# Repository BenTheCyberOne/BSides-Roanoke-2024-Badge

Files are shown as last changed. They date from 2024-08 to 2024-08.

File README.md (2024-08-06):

# Bsides Roanoke 2024 Badge
Public repo for the firmware source code, design files, and puzzle answers regarding the Bsides Roanoke 2024 Badge



## Index
/badge_fw: directory containing the badge's firmware and required libraries

/kiosk_fw: directory containing the kiosk's firmware and required libraries

/kiosk_server: directory containing the kiosk web application (scoreboard)

/badge_puzzles: directory containing the badge's puzzles and solutions

/badge_pcb: directory containing the badge's KiCAD design files

/badge_3d_parts: directory containing the badge's 3D printing (CAD) files

/kiosk_3d_parts: directory containing the kiosk's 3D printing (CAD) files

/results: directory containing the results of the BSides Roanoke 2024 Badge challenge

## Credits
This badge could not have been completed without the efforts of those below. Kudos to them!
- BenTheCyberOne
- Doc
- KoopaTroopa8

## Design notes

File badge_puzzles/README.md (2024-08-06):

# Badge Puzzle Solutions
Directory that holds the badge puzzles and their respective solutions. 

## Index
/Lights: Contains the puzzles, solutions for the light patterns that appeared in Puzzle Mode

/Printed: Contains the puzzles, solutions for the printed puzzles that appeared physically on the badge

/Serial: Contains the puzzles, solutions for the puzzles presented when using the serial commands in the badge

In total there were 11 puzzles (5 printed puzzles, 3 light puzzles inside of Puzzle Mode and 3 serial puzzles)

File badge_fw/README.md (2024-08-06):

# Badge Firmware
This directory holds the firmware and required libraries for the BSides Roanoke 2024 Badge

## ino
Because this firmware was built using Arduino IDE, the firmware is contained in one large .ino file. Arduino IDE made this firmware easy to develop, especially since I have never done something like this before. While it turned out to be quite a double-edged sword, Arduino IDE makes development of firmware for these small controllers quite an easy process. This folder also contains the compiled binary of the firmware, should you not want to build it yourself.

## lib
These are the external libraries used for the badge. 
- The PN532 library originally failed to function with our hardware, so alterations were made to ensure successful communication could happen between two badges.
- The NeoPixel library is unchanged and allows the NeoPixels on the board to function
- The EEPROM2 library is actually a modified version of the built-in "EEPROM" library of the Pico SDK. For some strange reason, there does not appear to be any libraries that allow easy control over sectors of flash via the rp2040. The original EEPROM library works by using up to the last 4KB of flash and storing it into RAM, allowing for quick read/write before commiting and saving to the real flash. EEPROM2 allows for sector selection (starting from the last 4KB sector). While not very memory-safe, it works perfectly for firmware that does not take a lot of space or code that does not utilize much of the RAM in the rp2040. Using this library (and a little computer science logic) we were able to quickly store and retrieve 3 different 4KB data structures stored in flash.

## How to build
1. Download Arduino IDE here: https://www.arduino.cc/en/software
2. Install the RP2040 device/board files: https://learn.adafruit.com/rp2040-arduino-with-the-earlephilhower-core/installing-the-earlephilhower-core
3. Ensure the libraries included in 'lib' are placed in your local Arduino IDE library file location
 	- "EEPROM2" should replace your builtin "EERPOM" library. This one is a bit more tricky to find, but on Windows should be somewhere like: C:\Users\User\AppData\Local\Arduino15\packages\rp2040\hardware\rp2040\3.9.2\libraries\EEPROM
4. Connect your Pico to your device and be sure to select the board type of "Raspberry Pi Pico" inside of Arduino IDE

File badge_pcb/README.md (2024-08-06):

# Badge Design Files

This directory holds a KiCAD 8 archive zip containing the necessary design files for the BSides Roanoke 2024 badge.

A few modded library items, along with SVGs for the badge's silkscreen patterns, puzzles and edge cuts are included as well

A PDF of the schematics has been created for easy access in this directory.

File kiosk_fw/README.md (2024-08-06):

# Kiosk Firmware
This directory holds the firmware and required libraries for the BSides Roanoke 2024 Kiosk

## ino
Because this firmware was built using Arduino IDE, the firmware is contained in one large .ino file. Arduino IDE made this firmware easy to develop, especially since I have never done something like this before. While it turned out to be quite a double-edged sword, Arduino IDE makes development of firmware for these small controllers quite an easy process. 

## lib
These are the external libraries used for the kiosk. 
- The PN532 library originally failed to function with our hardware, so alterations were made to ensure successful communication could happen between the badges and kiosk.

## How to build
1. Download Arduino IDE here: https://www.arduino.cc/en/software
2. Install the RP2040 device/board files: https://learn.adafruit.com/rp2040-arduino-with-the-earlephilhower-core/installing-the-earlephilhower-core
3. Ensure the libraries included in 'lib' are placed in your local Arduino IDE library file location
4. Connect your Pico to your device and be sure to select the board type of "Raspberry Pi Pico" inside of Arduino IDE

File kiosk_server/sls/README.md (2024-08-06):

# Crap I installed here

* Poetry to manage python bits
* Serverless framework for deployment

## First time install (future reference)

* npm install all the junk
* Install AWS Keys

```
serverless create-cert
serverless create_domain
```

## SLS resources

###  Dynamo Schema

Two tables.  

* users2024 - Users to track badge_id, username, team, scores, etc. Should be 
  small in size to enable scanning
* badges2024 - Badge table.  Basically the bulk upload, and only indexed by 
  badge. Used for auth and verification.  Might be pre-populated.

### Endpoints

All endpoints end in badge.bsidesroa.org

* 2024-bucket
    * Static hosting
* 2024-api
    * Api
* 2024
    * Primary webpoint for app.  Points to cloudfront, which fronts the
      2024-bucket

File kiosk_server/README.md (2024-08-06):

# Server

Place to house utilities and webservice for badge bits

## Directories

This has the following directories.

### API

The future state of the API, once defined.  It'll likely incorporate https://www.serverless.com/

### Console

A test CLI tool for mocking a badge kiosk.

### Graph Generator

A test script to do a video of handshakes.

### UI

Angular.

### Test Harness

Some demo pico python code to mock a bage reader for testing UI/Console.

## Poetry

All the python requirements for subdirectories should be managed with https://python-poetry.org/

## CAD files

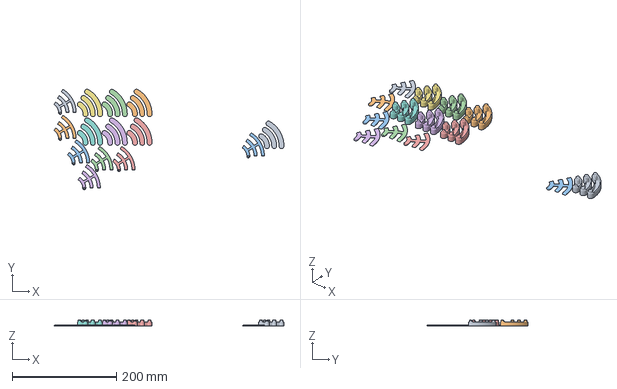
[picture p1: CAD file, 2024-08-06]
badge_3d_parts/lights/arc_v3.3mf
441.3 x 192.9 x 11.6 mm
arc_v8.stl x 7
backing_v4.stl x 7

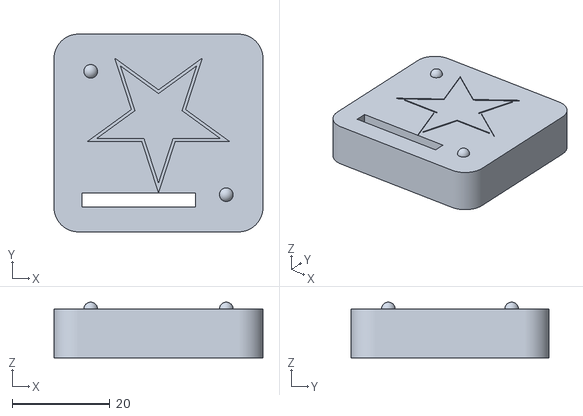
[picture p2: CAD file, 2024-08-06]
badge_3d_parts/support/support.stl
42.7 x 40.4 x 11.4

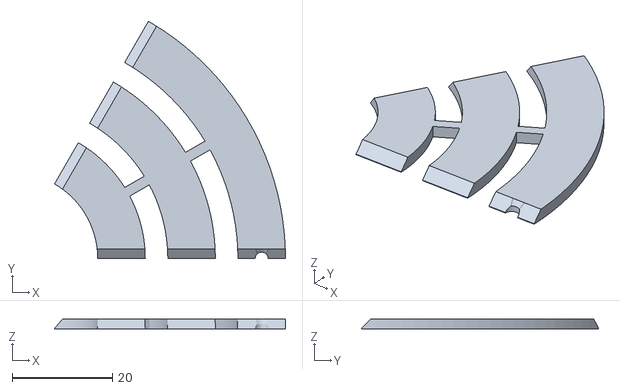
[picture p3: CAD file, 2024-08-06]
badge_3d_parts/lights/backing.stl
46.1 x 47.4 x 2.00

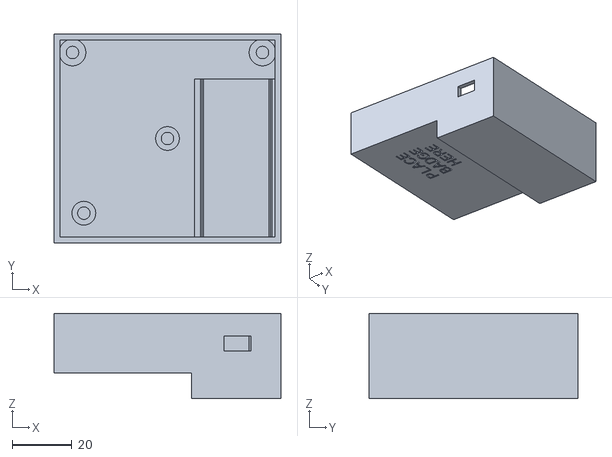
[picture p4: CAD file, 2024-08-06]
kiosk_3d_parts/TagScannerCasev03_pico_v3_bottom.stl
76.0 x 70.0 x 28.5

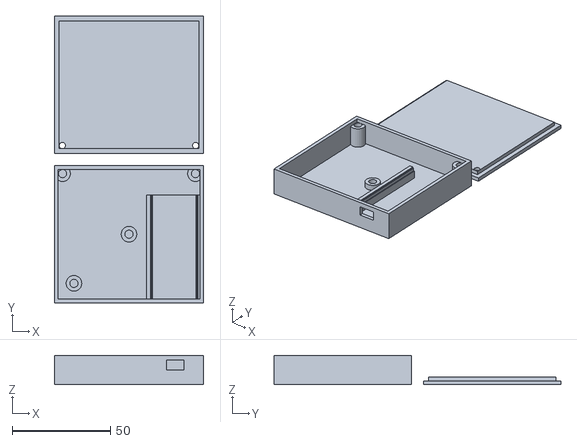
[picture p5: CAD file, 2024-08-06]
kiosk_3d_parts/TagScannerCasev03_pico_v4.stl
76.0 x 146.0 x 15.0

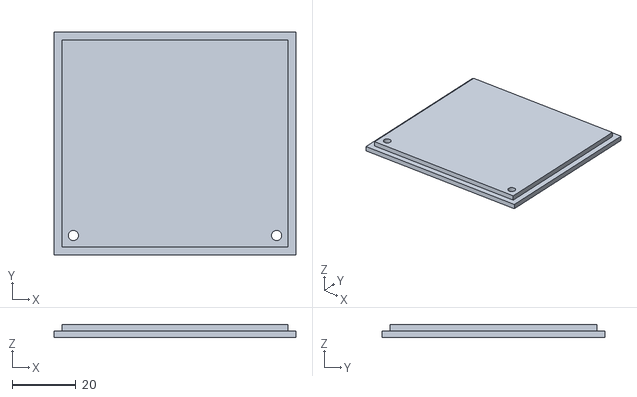
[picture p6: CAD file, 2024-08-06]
kiosk_3d_parts/TagScannerCasev03_pico_v3_top.stl
76.0 x 70.0 x 4.00

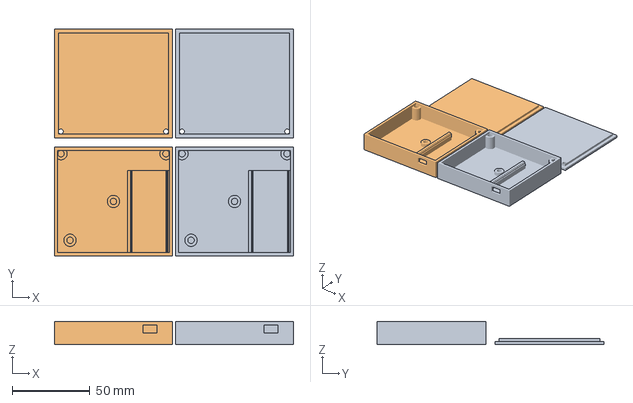
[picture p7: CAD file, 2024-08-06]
kiosk_3d_parts/TagScannerCasev03_pico.3mf
154.0 x 146.0 x 15.0 mm
TagScannerCasev03_pico_v4.stl x 2

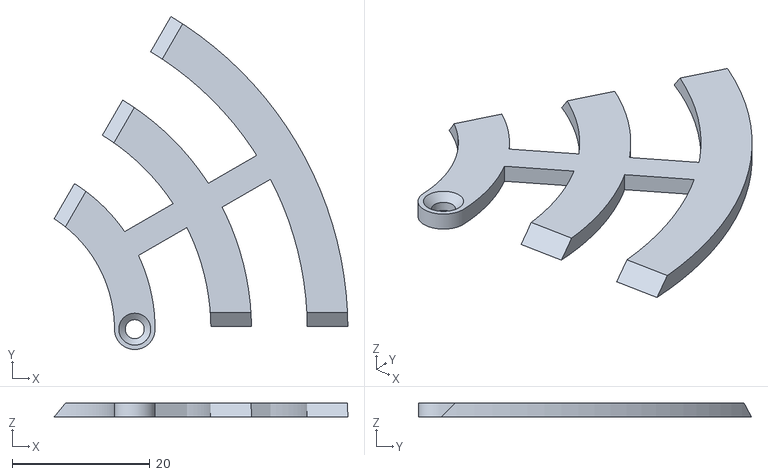
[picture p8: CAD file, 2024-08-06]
badge_3d_parts/lights/backing_v4.stl
42.6 x 48.3 x 2.00

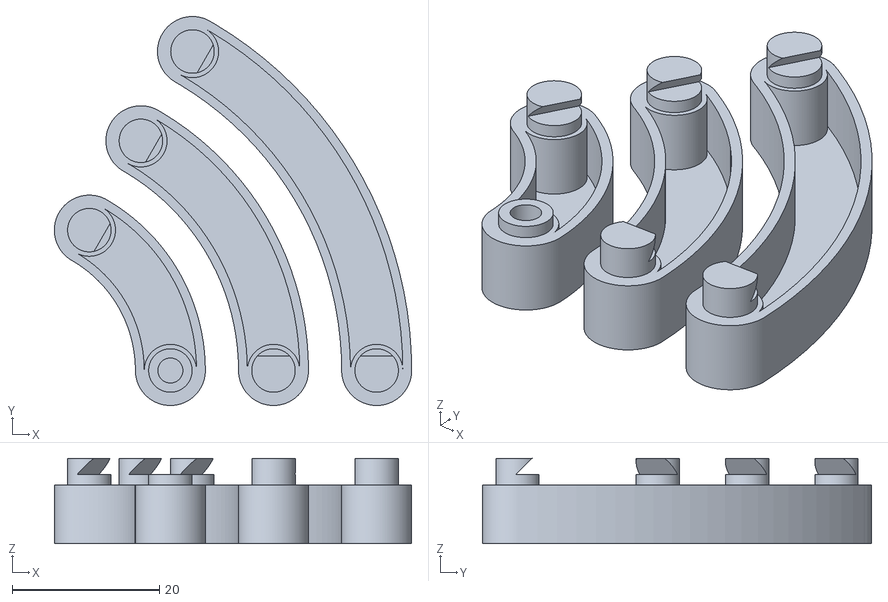
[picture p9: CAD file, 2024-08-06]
badge_3d_parts/lights/arc_v8.stl
48.5 x 52.8 x 11.6

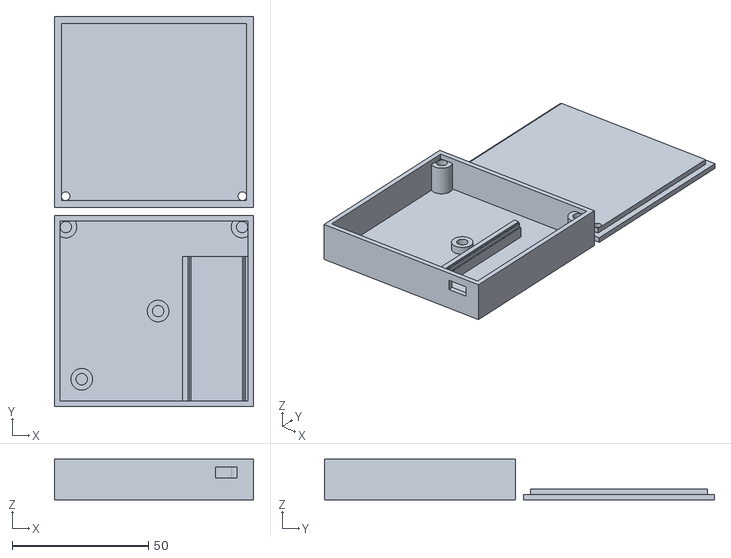
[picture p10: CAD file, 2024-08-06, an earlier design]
kiosk_3d_parts/TagScannerCasev03_pico_v2.stl
73.0 x 143.0 x 15.0

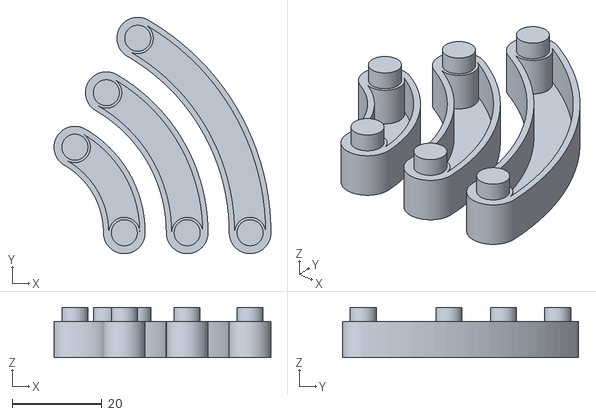
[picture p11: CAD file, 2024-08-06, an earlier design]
badge_3d_parts/lights/arc_v4.stl
48.3 x 52.6 x 11.2

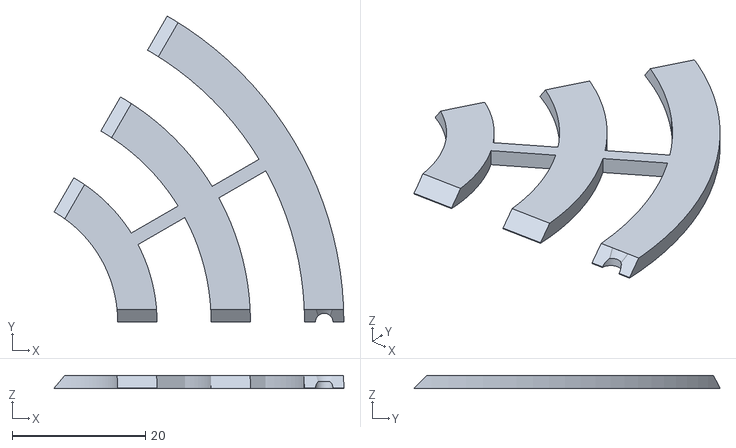
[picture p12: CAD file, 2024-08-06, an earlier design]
badge_3d_parts/lights/backing_v1.stl
43.4 x 45.9 x 2.00

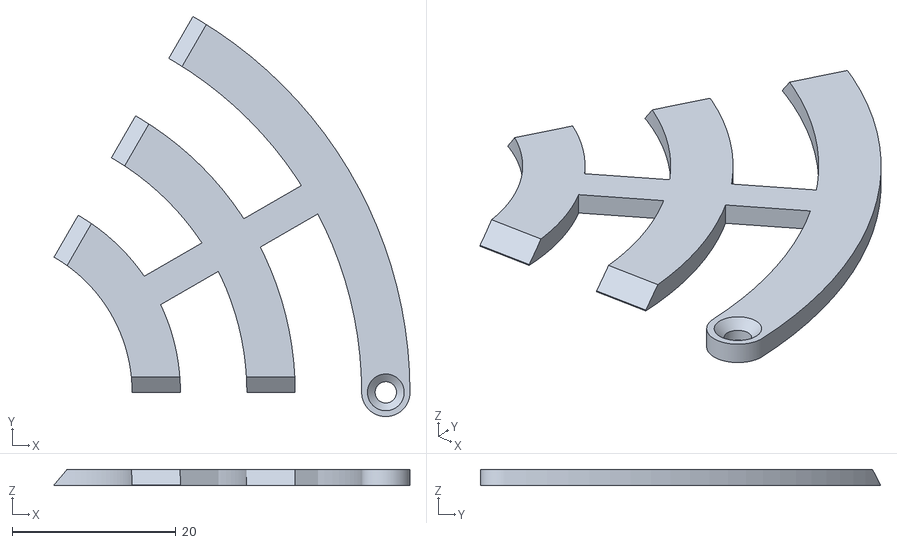
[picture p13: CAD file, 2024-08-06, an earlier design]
badge_3d_parts/lights/backing_v2.stl
43.4 x 48.8 x 2.00

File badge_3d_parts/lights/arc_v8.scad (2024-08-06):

/*
 * Draws an arc suitable for a badge.
 *
 *         \
 *  _    \  \
 * | | | |  |
 *  -    /  /
 *         /
 *  ^
 *  |
 *  Y  X->
 *
 * All units in mm.
 *
 * 2024/1/17
 * Aaron
 */


// Distance from center of badge to center of arc
r_dists = [44, 72, 100];

// Degrees of coverage
arclen=60;

// How high off the PCB?
height=8;

//Width of arc
width=6.3+3.2; // no idea how this got here.  But it seems to work?

// Wall thickness
z_wall_thickness=1.2;
//z_wall_thickness=.6;
xy_wall_thickness=1.2;

// render quality (16 is low, 64 is good)
fn=128;

// used to calculate the bottom portion of the knob clip
pcb_width=1.6;

// knob catch height/depth
knob_height=1.6;
knob_width=5.9;

back_height=2;

// downsizing backing until it works
backing_fudge = .15;

//m2.5 counter sunk head sizes
m25_cs_r2=(4.5+backing_fudge)/2;
m25_cs_r1=(2.6+backing_fudge)/2;


//m2.5 heat set insert
m25_hsi_r=(3.2+backing_fudge)/2;
m25_hsi_h=4.5+backing_fudge;



invert=0;

// CODE 
include <BOSL/constants.scad>
use <BOSL/shapes.scad>


module m25_cs(h) {
  delta=(m25_cs_r2-m25_cs_r1);
  threads_h=h-delta;
  union() {
    cylinder(threads_h, r=m25_cs_r1, $fn=fn);
    translate([0,0,threads_h-.001])
      cylinder(delta, r1=m25_cs_r1, r2=m25_cs_r2, $fn=fn);
  }
}

module lb(r_dist, width=width) {
  union() {
    difference() {
      arced_slot(d=r_dist, h=height, sd=width, sa=0, ea=arclen, $fn=fn, $fn2=fn);
      translate([0,0,z_wall_thickness]) {
        arced_slot(d=r_dist, h=height, sd=width-2*xy_wall_thickness, sa=0, ea=arclen, $fn=fn, $fn2=fn);
      }
    };
    
    // Restore ends for clip
    difference() {
      for (rot_angle = [0, arclen]) {
          rotate([0, 0, rot_angle]) {
            translate([r_dist/2, 0, 0]) {
              cylinder(h=height, r=width/2-xy_wall_thickness, center=true, $fn=fn);
            }
            difference() {
              translate([r_dist/2, 0, height/2-.01]) {
                cylinder(h=(pcb_width+back_height), r=knob_width/2, $fn=fn);
              }
              
              // brackets
              if(rot_angle == 0) {
                translate([r_dist/2-knob_width/2, knob_width-.2, height/2+pcb_width-.2])
                  rotate([0,0,-90])
                    right_triangle([knob_width, knob_width,knob_width]);
              } else {
                translate([r_dist/2-knob_width/2, -knob_width+.2, height/2+pcb_width-.2])
                rotate([0,-90,-90])
                  right_triangle([knob_width, knob_width,knob_width]);
              }
              

            }
          }
        }
        // lop off top
        translate([r_dists[0]/2-knob_width/2, 0, height/2+knob_height-.2])
          cylinder(10,10);
        // bore hole for heat set insert
        translate([r_dists[0]/2, 0, height/2+pcb_width-.1-m25_hsi_h])
          cylinder(m25_hsi_h+2, r=m25_hsi_r, $fn=fn);
    }
    
    
    
    
    /*
    for(rot=[0, arclen]) {
      rotate([0,0,rot]) {      
        // first knob
        translate([r_dist/2, 0, height*.25]) {
          color("grey")
          arced_slot(d=width-2.9*xy_wall_thickness, 
                     h=3*(pcb_width+knob_height*2+knob_depth), 
                     sd2=knob_width,
                     sd1=0,
                     sa=185+(180/arclen)*rot, 
                     ea=265+(180/arclen)*rot, 
                     $fn=fn, $fn2=fn);
                     
          //color("green")
        }
      }
    }*/
  }
}

// full render
module light_bar_full(width=width) {

  union() {
    for(i=r_dists) {
      lb(i, width=width);
    }
  }
}

module backing() {
  difference() {
    union() {
      // arc_axials
      linear_extrude(back_height) {
        intersection() {  
          translate([0,0,0])
            projection(cut=false)
              light_bar_full(knob_width);
              
          projection(cut=false)
            union() {
              pie_slice(arclen, h=1, r=r_dists[2]/2+10);
              translate([20,0,0])
                  cylinder(10, 5, center=true);
            }
        }
      }

      // connecting arm
      rotate([0,0,arclen/2])
        translate([r_dists[0]/2, -back_height, 0])
          cube([(r_dists[2]-r_dists[0])/2, back_height*2, back_height]);
      
    }
    color([1,0,0])
    // right_triangle([width, thickness, height], [orient], [align|center]);
    translate([0,0,back_height+1])
      rotate([0,90,-30])
        translate([.5,0,-.6])
          right_triangle([back_height+2, r_dists[2]/2+10, back_height+2]);
          
    color([1,0,0])
    translate([0,0,back_height+1])
      rotate([0,180,-90])
        translate([-.6,30,0])
          right_triangle([back_height+2, r_dists[2]/2+10, back_height+2]);
    
    // screw hole
    color([1,0,0])
    translate([r_dists[0]/2, 0, -.1])
      m25_cs(back_height+.11);

  }
}


//*** back brace
backing();



//*** light bars
//light_bar_full();

//****individual render
//lb(r_dists[0]);

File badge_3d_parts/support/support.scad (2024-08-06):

/*
 * PN532 Support
 * 
 */
 
 include <BOSL/shapes.scad>;
  include <BOSL/constants.scad>;
 
// sourced from https://www.elechouse.com/elechouse/images/product/PN532_module_V3/PN532_shematic_drowing.pdf
x = 42.7;
y = 40.4;

z = 10;
 
  
hole_size = 3;
hole_centers = [
 [x-7.5, 7.6],
 [7.5, y-7.6]];

header_y_len = 2.8;
header_x_len = 2.54*(8+1)+.3;

header_centerx = x - (15.1-2.54/2 + header_x_len/2);
header_centery = 6.52;

union() {
  difference() {
    cuboid(
      [x,y,z], fillet=5,
      edges=EDGE_FR_RT+EDGE_BK_RT+EDGE_BK_LF+EDGE_FR_LF, 
      $fn=256
      );
      
    translate([header_centerx-x/2, header_centery-y/2, 0]) {
      cube([header_x_len, header_y_len, z+10], center=true);
    }
  }
  
  for (hc = hole_centers) {
    translate([hc[0]-x/2, hc[1]-y/2, z/2]) {
      sphere(hole_size/2, $fn=128);
    }
  }
}

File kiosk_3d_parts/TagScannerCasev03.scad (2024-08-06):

// Case for a nano and PN532
// mjf 6/26/2017
$fn=24;
caseH = 15;
caseW = 65;
caseL = 75;
//PN532W = 40;
//PN532L = 43;
NanoW = 19;
NanoL = 43;
NanoBlock = 23 ; 
wallThick = 2;
clearance = .5;
arbitrary = -3; // some arbitrary height above the base


//////////////// Start of Letter Module //////////////////////////////
// found on https://github.com/KitWallace/openscad/blob/master/liddedHeartBox.scad
font = "Liberation Sans";

letter_size = 5;
letter_height = 1;


module letter(l) {
	// Use linear_extrude() to make the letters 3D objects as they
	// are only 2D shapes when only using text()
	linear_extrude(height = letter_height) {
		text(l, size = letter_size, font = font, halign = "center", valign = "center", $fn = 16);
	}
}

//////////////// End of Letter Module //////////////////////////////

module post(x, y, bigPost, smallPost){
    difference(){
    translate([-caseL/2 + wallThick + x ,-caseW/2 +wallThick + y ,0])
        cylinder(r=bigPost, h=wallThick +3);
    translate([-caseL/2 + wallThick + x ,-caseW/2 +wallThick + y ,0])
        cylinder(r=smallPost, h=wallThick +3);
    }
    
}

module nano(Xoffset, Yoffset, Zoffset){
    difference () {
        // main block
        translate([Xoffset,Yoffset,0 + Zoffset])
            cube ([NanoBlock,NanoL,8.6], center=true);
        // cut out
        translate([Xoffset,Yoffset,2+ Zoffset])
            cube ([NanoW-2,NanoL+1.5,8], center=true);
        // nano slot
        translate([Xoffset,Yoffset,4+ Zoffset])
            cube ([NanoW-1,NanoL+1,3.6], center=true);      
        // header pin slot
        translate([Xoffset,Yoffset,5.5+ Zoffset])
            cube ([NanoW,NanoL+1,3.6], center=true);
    }     
}

module base(){
    difference(){
        translate([0,0,.5*caseH]) 
            cube([ caseL, caseW,  caseH], center = true);
        translate([0,0,.5*caseH + wallThick]) 
            cube([ caseL-2*wallThick, caseW-2*wallThick,  caseH], center = true);
        translate([caseW/2 -NanoBlock/2 ,-caseW/2 -1 ,8])
            cube([8,wallThick+2,4]); //USB hole
        
    /////////Letters ///////////////////////////////////
        translate([-22, 0, .9]) rotate([0, 180, 90]) letter("P");
        translate([-22, -5, .9]) rotate([0, 180, 90]) letter("L");
        translate([-22, -10, .9]) rotate([0, 180, 90]) letter("A");
        translate([-22, -15, .9]) rotate([0, 180, 90]) letter("C");
        translate([-22, -20, .9]) rotate([0, 180, 90]) letter("E");
        translate([-15, -5, .9]) rotate([0, 180, 90]) letter("T");
        translate([-15, -10, .9]) rotate([0, 180, 90]) letter("A");
        translate([-15, -15, .9]) rotate([0, 180, 90]) letter("G");
        translate([-8, -3, .9]) rotate([0, 180, 90]) letter("H");
        translate([-8, -8, .9]) rotate([0, 180, 90]) letter("E");
        translate([-8, -13, .9]) rotate([0, 180, 90]) letter("R");
        translate([-8, -18, .9]) rotate([0, 180, 90]) letter("E");
    }
    post(x = 8, y=8, bigPost = 2.5, smallPost = 1.25);
    post(x = 36, y=33, bigPost = 2.5, smallPost = 1.25);
}


module top(){
    union() {
        translate([0,0,caseH + arbitrary + wallThick]) 
            cube([ caseL-(2*wallThick +2*clearance), caseW-(2*wallThick + 2*clearance),  wallThick], center = true); //bottom
        // difference(){   
            translate([0,0,caseH + arbitrary  + 2* wallThick])
                cube([ caseL, caseW, wallThick], center = true); //top
          /*  translate([0, 10, 17.4]) rotate([180, 0, 90]) letter("M");
            translate([0, 5, 16.4]) rotate([0, 00, 270]) letter("J");
            translate([0, 0, 16.4]) rotate([0, 00, 270]) letter("F");
            translate([0, -5, 16.4]) rotate([0, 00, 270]) letter("5");
            translate([0, -10, 16.4]) rotate([0, 00, 270]) letter("5");
         }*/
    }
    
}


base();
nano(Xoffset = caseL/2 - wallThick  - NanoBlock/2 +1 , Yoffset= -caseW/2  +NanoL/2 +wallThick , Zoffset = 4.3);

//top();

rotate([0,180,0])
	translate([0,caseL-5, -(caseH + arbitrary  + 2*wallThick+ 1.2)]) //dont know why 1.2 makes it on 0 plane
		top();

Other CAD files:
badge_3d_parts/lights/arc_v6.stl
badge_3d_parts/lights/arc_v7.stl
kiosk_3d_parts/TagScannerCasev03_pico_v3.stl
badge_3d_parts/lights/backing_v3.stl
kiosk_3d_parts/TagScannerCasev03_pico.scad
badge_3d_parts/lights/arc_v1.scad
badge_3d_parts/lights/arc_v3.scad
badge_3d_parts/lights/arc_v3.stl
badge_3d_parts/lights/arc_v4.scad
badge_3d_parts/lights/arc_v5.scad
badge_3d_parts/lights/arc_v6.scad
badge_3d_parts/lights/arc_v7.scad
kiosk_3d_parts/TagScannerCasev03_pico.stl
kiosk_3d_parts/TagScannerCasev03_pico_v2.scad
kiosk_3d_parts/TagScannerCasev03_pico_v3_bottom.scad

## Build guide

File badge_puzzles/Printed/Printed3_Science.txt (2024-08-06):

"Science" is found under the arc axial spine support on the back of the badge. The arc axial spine support must be taken off via screwdriver at the respective screw hole.

1. Under each axial is a handful of words that may look familiar to those who frequent chemistry/physics. 
"Phosphorus Erbium Iodine Oxygen Deuterium Iodine"
"Carbon Plutonium Z-boson Z-boson"
"Lepton Einsteinium"

2. Let's try matching these to their periodic symbols. Z-boson and Lepton don't look like elements though. Looking up Deuterium shows us that it isn't an element either, but rather an isotope of Hydrogen. It may be important that each word starts with a capital letter. Let's try just using the captial letter of the non elements and see what we can get.

"P(hosphorus) Er(bium) I(odine) O(xygen) D(euterium) I(odine)"
"C(arbon) Pu(Plutonium) Z(boson) Z(boson)"
"L(epton) Es(Einsteinium)"

3. Put it together and we get: PErIODICPuZZLEs

Flag: PErIODICPuZZLEs

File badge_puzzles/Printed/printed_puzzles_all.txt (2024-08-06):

1. Befunge-93 Programming
Answer: gR4ph1K_D33ziGN
Puzzle:
99*73*1++,v
v,++2*8+55<
>96*2-,93+v
v5*45,+4*9<
>*4+,77*,7v
v1+99,*5+8<
>+5*,88+1+v
v1*5+55,*4<
>+,55+5*1+v
v2*+55*26,<
>+,73*5*,9v
v6*89,-1*8<
>+,@

2. ROT-2 (or ROT-28)
Answer: R1ng_4round_th3_R0T
Puzzle:
P1le_4pmslb_rf3_P0R

3. Periodic Symbols
Answer: Periodic Puzzles
Puzzle:
Phosphorus Erbium Iodine Oxygen Deuterium Iodine Carbon Plutonium Z-boson Z-boson Lepton Einsteinium

4. Rattlesnake
Answer: aR@TTl3RATTLe_RatT13z_M33
Puzzle: (Base64)YVJAVFRsM1JBVFRMZV9SYXRUMTN6X00zMw
    Y
   (")
   V\\w
    J\\M
     A))z
    V//0
   F//0
  R((X
   s\\6
    M\\N
     1\\T
      J))M
     B//U
    V//R
   F//X
   R((Y
   M\\S
    Z\\9
      V

5. Wingdings
Answer: D1ngz_0n_th3_WING
Puzzle:
👎︎📂︎■︎♑︎⌘︎♉︎📁︎■︎♉︎⧫︎♒︎🗏︎♉︎🕈︎✋︎☠︎☝︎

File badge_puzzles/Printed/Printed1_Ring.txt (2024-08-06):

"Ring" is located at the top lefthand side of the front of the badge. These character patterns may look weirdly familiar to those who have participated in CTFs before.

1. The "Ring" is unspun is as follows: P1le_4pmslb_rf3_P0R

2. Ring = Circle = Rotation (ROT)

3. Attempting to use the classic ROT13 (caesar cipher) does not appear to show anything of use (ROT13{P1le_4pmslb_rf3_P0R} = C1yr_4czfyo_es3_C0E). Let's try starting from ROT1 and incrementing until we find something!

ROT1{P1le_4pmslb_rf3_P0R} = Q1mf_4qntmc_sg3_Q0S
ROT2{P1le_4pmslb_rf3_P0R} = R1ng_4round_th3_R0T

ROT2 gave us some fitting text!

Flag: R1ng_4round_th3_R0T

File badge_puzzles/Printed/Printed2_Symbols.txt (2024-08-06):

"Symbols" is located near the bottom of the back of the badge, under the battery pack.

1. These symbols don't look random, and are unique except for one character which is repeated 3 times. This might tell us they are substituted for a human readable string
Symbols: 👎︎📂︎■︎♑︎⌘︎♉︎📁︎■︎♉︎⧫︎♒︎🗏︎♉︎🕈︎✋︎☠︎☝︎

2. Time to do some googling! Let's try searching for:
weird symbol cipher
symbols fonts
symbols ctf
cryptography weird symbol cipher

3. We should stumble upon the "Wingdings" font - used almost exclusivly for Microsoft to display symbols instead of letters. Look up a translator or pull up the direct character mapping and we can easily decode the symbols into readable text!

👎︎📂︎■︎♑︎⌘︎♉︎📁︎■︎♉︎⧫︎♒︎🗏︎♉︎🕈︎✋︎☠︎☝︎ = D1ngz_0n_th3_WING

✡︎♏︎♋︎♒︎📪︎ ♓︎⧫︎ ♓︎⬧︎ ♋︎ ⬧︎●︎♓︎♑︎♒︎⧫︎ ■︎□︎♎︎ ⧫︎□︎ 🕆︎■︎♎︎♏︎❒︎⧫︎♋︎●︎♏︎

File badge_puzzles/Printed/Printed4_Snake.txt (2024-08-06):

"Snake" is found on the right-hand side on the front of the badge, right beside the PN532.

1. The characters found around the snake may look quite familiar to those who deal with this common encoding scheme. Seeing as we only have a basic character set of A-Z, a few numbers, and repeating characters it might be safe to say this string around the snake is encoded with something like Base64. This might not matter though as we don't have any indication of where this string appears to start!

    Y
   (")
   V\\w
    J\\M
     A))z
    V//0
   F//0
  R((X
   s\\6
    M\\N
     1\\T
      J))M
     B//U
    V//R
   F//X
   R((Y
   M\\S
    Z\\9
      V

2. We can of course take all the characters and attempt to bruteforce the answer by lining them up in all kinds of ways, but that could take ages. Let's try to think more simple about this. Instead of reading each character left to right, let's try reading each character top to bottom. Don't be fooled by this serpent - It's tongue and tail are characters too!!

Base64{YVJAVFRsM1JBVFRMZV} = aR@TTl3RATTLe
YwMz00X6NTMURXYS9V = non-ASCII gibberish

3. From the left side of the snake going from tongue to tail, we get a part of the flag! The right hand side however does not give us the other half. Instead of going from top to bottom on the right side, let's slither like a snake and go from the top of the left side down to the tail, then back up the right side!

Base64{YVJAVFRsM1JBVFRMZV9SYXRUMTN6X00zMw} = aR@TTl3RATTLe_RatT13z_M33

Flag: aR@TTl3RATTLe_RatT13z_M33

bm9uYWdvbiBpbmZpbml0eSBvcGVucyB0aGUgZG9vcg==

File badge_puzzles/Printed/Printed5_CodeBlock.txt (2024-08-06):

"CodeBlock" is found underneath the PN532 on the front of the badge. The PN532 and it's base support can be easily pulled off to reveal the block of code underneath.

This one was fun to learn and make. It was originally significantly more difficult, but would have required graph paper to complete. As such, I made it possible to solve via the online compilers for Befung. 

1. The characters inside this block appear to be strictly numbers and symbols. We mainly see a bunch of *, +, -, and of course a ton of <, >, and v. Let's type it out as to not strain our eyes too much:

99*73*1++,v
v,++2*8+55<
>96*2-,93+v
v5*45,+4*9<
>*4+,77*,7v
v1+99,*5+8<
>+5*,88+1+v
v1*5+55,*4<
>+,55+5*1+v
v2*+55*26,<
>+,73*5*,9v
v6*89,-1*8<
>+,@

At first glance, it might look like one long weird math problem.

2. The title of this puzzle is "CodeBlock", so this must be some kind of code that is just super hard to read? Maybe it is obfuscated or an odd language? There are a ton of things you can try to google here, and will take up nearly all of your time on this puzzle. Here are a few suggestions:

weird programming language code
code block language "<" ">" math
programming language "<"

3. You should eventually stumble upon the great world of Esoteric programming languages (esolang). Esolang are mainly joke languages that - while completely functional - are often hard or impossible to understand without significant knowledge of the syntax. A wikipedia can be found for most of these insane pseudolanguages here: https://esolangs.org. You may find that the "Befunge" esolang characters match directly with the block of code on our badge. Time to learn Befunge!

4. Let's start by reading a quick rundown at https://esolangs.org/wiki/Befunge. Befunge is the first "2D" programming language that can actually mutate during runtime! It is 2D in the sense that the instructions can be read from left to right, right to left, top to bottom, and bottom to top! Different characters (>, <, ^, V) change the reading direction of the running code, while other characters (+,-,*,/,) modify/pop numbers and push it onto the stack. You even have the ability to "get" a value from your graph and "put" a value from your stack anywhere on the graph. I highly advise you take a look at this language and attempt to decode the block using the syntax provided from the wiki. There is some fun math involved and it will help you learn how to use this awesomely useless language. 

5. Or, we can just use an online compiler since we now know it is a block of code written in Befunge:  https://www.tutorialspoint.com/compile_befunge_online.php

Compiling the code, we get the following string output: gR4ph1K_D33ziGN

Flag: gR4ph1K_D33ziGN

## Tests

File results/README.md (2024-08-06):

# Result from Event

These are the results from BSides Roanoke 2024 Badge Challenge.  In this
challege, players had an electronic badge with an PN532 NFC device.  Each badge
could pair, or find environmental NFC tags for points.  To score, players would
use their NFC Badge at a kiosk to upload their results for scoring.  This dump
of data is based on the uploaded results.

## badge\_data\_raw Folder

This folder contains raw data from the checkin from the players that checked in
at a badge kiosk.  Not all players checked in, so some data is likely missing.

Filenames are structured as:

    1720795265-08A08888.json
    \          \
     \          \- Badge ID, as read by Kiosk
      \
       \- Linux Epoch Time at time of API call.  For example, this dump was
          created at:
          Friday, July 12, 2024 10:41:05 AM GMT-04:00 DST

The structure of these files would contain JSON looking something like:

    {
      "badge_id": "08A04AE3",
      "hst": "309693A0D9AD3059FCA02BB830D7A030D7A030DA4F3025703056FDA06E5F3073AAA09719",
      "wt": "0001EB0006EC0008EA0009EB",
      "st": "08A0D99308A0D99308A07769"
    }

The `badge_id` is described in more detail below.

The `hst` or Hand Shake Table is the primary table to track handshakes.  It's 
composed of 3-byte badge\_ids (omitting `0x08`) either in it's normal form or
XOR'd form. There may be a bug somewhere in the kiosk or badge that alternates
normal and XOR'd form. There may be duplicates within the table, but only
uniques are counted for scoring.

The `wt` or Worm Table describes the path of each worm.  The first 2 bytes are
the index into the `hst` for which badge infected it. The last byte is the
value for the worm.  

Attendees would be white value if not associated with a worm.  When pairing
badges, a worm check would be performed to compare any associated worm values.
If an attendee did not have a worm value, they would assume their peer's worm.
Otherwise, the worm would follow a rock-paper-scissors game, where each value is
assigned rock, paper, or scissors.

Worm Values:

| Worm Value | LED Colors | Gets Beat By | Beats  | RPS Term |
| --- | --- | --- | --- | --- |
| `0xEA` | Orange | `0xEB` | `0xEC` | Rock |
| `0xEB` | Blue | `0xEC` | `0xEA` | Paper |
| `0xEC` | Purple | `0xEA` | `0xEB` | Scissors |

The `st` is the Scan Table, to capture environmental reads of static NFC tags.
It should be referenced against the file `scanlist`.

If you use `sls/lib/part_handler.py`, you can decode some of a little easier.
It takes the `hst`, `wt`, and `st` as arguments. See example below.
```
$ python3 sls/lib/part_handler.py \
  "309693A0D9AD3059FCA02BB830D7A030D7A030DA4F3025703056FDA06E5F3073AAA09719" \
  "0001EB0006EC0008EA0009EB" "08A0D99308A0D99308A07769"

{
  "handshakes": [
    "A00D0C",
    "A0D9AD",
    "A0C263",
    "A02BB8",
    "A04C3F",
    "A04C3F",
    "A041D0",
    "A0BEEF",
    "A0CD62",
    "A06E5F",
    "A0E835",
    "A09719"
  ],
  "unique": 11,
  "packed_hst": "309693A0D9AD3059FCA02BB830D7A030D7A030DA4F3025703056FDA06E5F3073AAA09719",
  "encrypted": true
}
{
  "worms": [
    {
      "badge_ref": 1,
      "worm": "EB"
    },
    {
      "badge_ref": 6,
      "worm": "EC"
    },
    {
      "badge_ref": 8,
      "worm": "EA"
    },
    {
      "badge_ref": 9,
      "worm": "EB"
    }
  ],
  "current_worm": "EB",
  "packed_wt": "0001EB0006EC0008EA0009EB"
}
{
  "scans": [
    "08A0D993",
    "08A0D993",
    "08A07769"
  ],
  "failed_scans": [],
  "packed_st": "08A0D99308A0D99308A07769"
}
```

### Badge IDs

Badge IDs are the unique identifiers for each badge type. They compose of 3-4
bytes

_First Byte_ is being optional and is an artifact from the PN532 `0x08`. It's
only an artifact from the kiosk reading the badge.

_Second Byte_ defines the badge category, and is either `0xA0` for attendees or
or `0xB0` for sponsors.

_Third and fourth byte_ are the unique identifiers per badge.  While seemingly
small, there are 65536 possible badge IDs per category.  The attendee category
had 131 entries, giving a .2% chance of guessing badge ID correctly for
manipulation.  This should enable us to see audit activity if something were to
go sideways if someone figured out the API.

Badge IDs may be also seen as being XOR'd with the key of `0x909b9f`.

A full list of supported badges is in the file **badgelist**.

## badgelist

A list of all the badges used within the event.  Notable badges are:

* A00D0C - doc's badge.  Has the worm `0xEB`
* A08888 - koopatroopa's badge.  Has worm  `0xEC`
* A0BEEF - Organizer's badge.  Has worm `0xEA`
* A0DEAD - BenTheCyberOne's badge.  Has worm `0xEA`

## scanlist

A list of environmental NFC tags from the event.

## scores.json

The json file that fed the scoreboard on the website.  This had the resulting
score of each user that had scanned their badge. This file was regenerated upon
scoring.

## teams.json

The `teamId` to CTF's `teamName` json file.  Fetched from the CTF instance
periodically.

**Note:** Team names have been adjusted to remove names.  What was a name like
`Bob Smith` has been reduced to `BS`.

## secret\_scoreboard.csv

A CSV containing the highest scoring team member to Team Name.

## website/*

A dump of the static website.

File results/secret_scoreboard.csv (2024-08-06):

Team Name | Max Badge Score
DadTheCyberOne | 10
Team MC | 10
Team RH | 0
Ham On Biscuits | 0
Team JH | 0
luuz3r | 0
Monstas | 10
xAptive | 0
Team JayR | 7
Team ZG | 0
Team BL | 7
Team DS | 0
Team AB | 0
Team SF | 0
Team ES | 0
Team B,H | 0
Team NT | 0
Team Self Esteem | 42
a team name | 0
Team SM | 0
Laffsec | 0
Team TB | 9
Team MU | 0
Team AM | 0
Team ME | 0
HII | 4
Team ZTS | 0
RUSecure? | 12
Team H | 0
blue_ph0enix | 0
Team HA | 0
Team DC | 0
Hash Slinging Hackers | 0
Team t | 0

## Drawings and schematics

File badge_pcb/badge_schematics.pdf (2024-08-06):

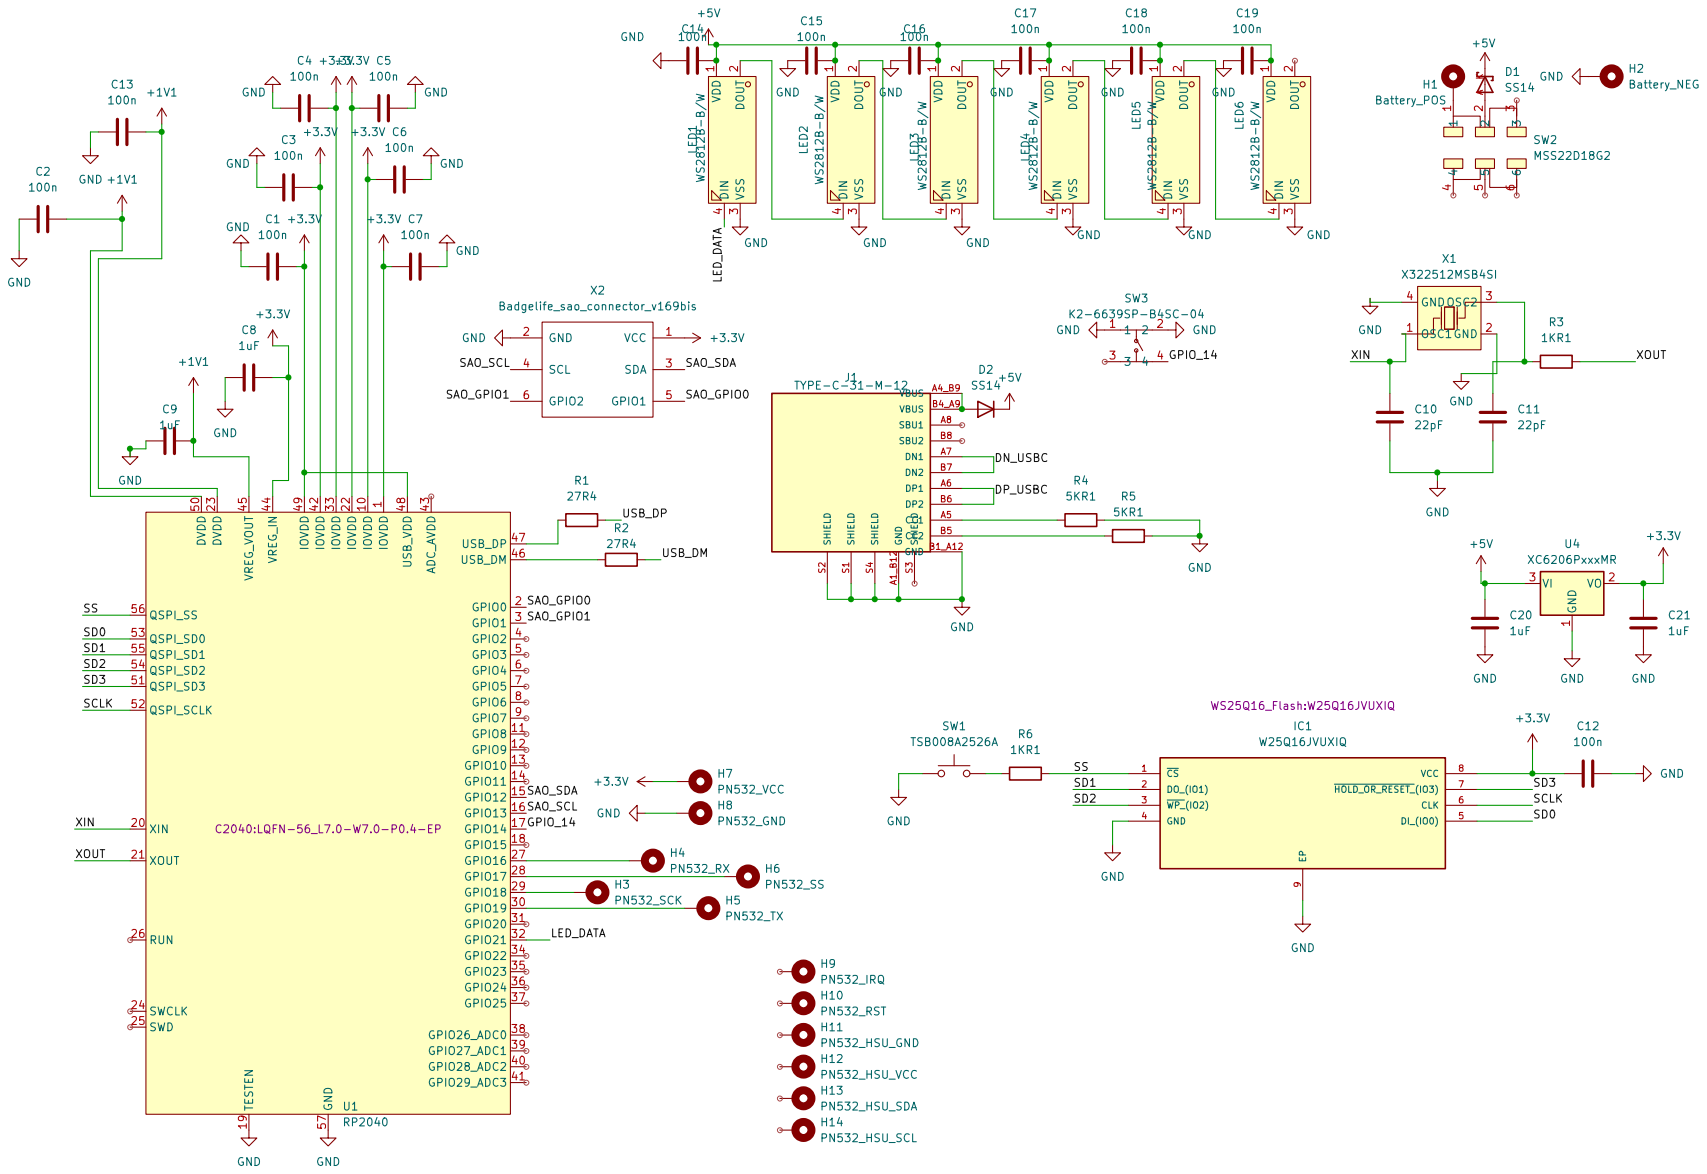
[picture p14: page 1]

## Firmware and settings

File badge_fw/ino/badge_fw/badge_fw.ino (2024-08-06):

/*
BSides Roanoke 2024 Badge FW
Wrote by BenTheCyberOne with the help of doc and KoopaTroopa8

Free to edit and distribute as you please

                      Badge UIDs
      +------------+---------------+-----------+
      |  Required  |  BADGE_TYPE   |    UID    |
      +------------+---------------+-----------+
      |    0x08    | 0xA, 0xB, 0xC | 0xXX 0xYY |
      +------------+---------------+-----------+

                  Worm Record Entry
      +----------------------+------------------+
      |  Pair Table Record   |    Worm Value    |
      +----------------------+------------------+
      |      0xXX 0xYY       | 0xEA, 0xEB, 0xEC |
      +----------------------+------------------+

Badge pairing happens over the course of 8 different functions due to how NFC P2P works on the PN532
First, two badges will share each other's UIDs. This is done with one badge being the "initiator" and the other the "target".
Each badge swaps between being the target and initiator until they both receive the message of "hello from {UID}".
To prevent any possible replay attack, both badges go through this cycle once more however sending over the message in an encrypted format
(same message, just XOR'd with the key of: 0x909B9F8C). The message however also contains a "worm" value. This is what changes the badge's light colors.
If the decrypted UID does not match the one obtained in the previous P2P cycle, the pairing fails and we know we are not talking to a real badge.

*/
#include "SPI.h"
#include "PN532_SPI.h"
#include "llcp.h"
#include "snep.h"
#include <Adafruit_NeoPixel.h>
#include <NfcAdapter.h>
#include <EEPROM.h>      //simulate EEPROM by taking last sector of flash and emulating into RAM. Saves to flash on commit()
#include <MD5Builder.h>  //MD5 lib to fix the easy hack of changing your own UID to someone else's

#define PIN 21         //GPIO for NeoPixels
#define BUTTON_PIN 14  //GPIO for mode select button
#define NUMPIXELS 6   //Number of NeoPixels on the board
#define UIDLENGTH 3  // first byte is hardcoded, so 3 free bytes for UID
#define M1LENGTH 11  //"hello from " = 11
#define MODE_PAIR 1  
#define MODE_SCAN 2
#define MODE_KIOSK 3
#define MODE_PUZZLE 4
// The definitions below are no longer utilized since we are using a modified version of <EEPROM>, allowing for a full sector for each table
//#define PAIR_TABLE_OFFSET 0       //Pair table in flash starts at 0 (1502 bytes total)
//#define WORM_TABLE_OFFSET 1501    //Worm table in flash starts at 1501 (1502 bytes total)
//#define SCAN_TABLE_OFFSET 3003    //Scan table in flash starts at 3003 (1025 bytes total)
//#define CURRENT_WORM_OFFSET 4090  //Byte to store current worm value at 4090 (1 bytes total)
#define PAIR_TABLE_SECTOR 0
#define WORM_TABLE_SECTOR 1
#define SCAN_TABLE_SECTOR 2
#define PAIR_TABLE_OFFSET 0
#define WORM_TABLE_OFFSET 0
#define SCAN_TABLE_OFFSET 0
#define CURRENT_WORM_OFFSET 4095  //very last byte of the Worm Table since we get an even 1364 enteries if we save 2 bytes for the record and 1 byte for Worm (4096 - 3)/3 = 1364

#define RPS_ROCK 0xEA
#define RPS_PAPER 0xEB
#define RPS_SCISSORS 0xEC

// XOR'd UID
uint8_t uid[3] = { 0x30, 0x25, 0x70 };

// Global secret message buffer
uint8_t secret[5] = { 0x08, 0, 0, 0, 0 };

//Global XOR key buffer
uint8_t k[4];

//Function prototypes otherwise Arduino IDE yells at us
void getPairTable(uint8_t *buffer, bool copyAll);
void getWormTable(uint8_t *buffer, bool copyAll);
void getScanTable(uint8_t *buffer, bool copyAll);

//how we will limit the amount of times getCurrentWorm needs to be called:
uint8_t currentWorm = 0xFF;

Adafruit_NeoPixel pixels(NUMPIXELS, PIN, NEO_GRB + NEO_KHZ800);
PN532_SPI pn532spi(SPI, 17);
SNEP nfc(pn532spi);
MD5Builder md5;

//setup tableBuf1-3 in setup to ensure correct allocation during startup/runtime. Three required for Kiosk functions
uint8_t tableBuf1[4096];
uint8_t tableBuf2[4096];
uint8_t tableBuf3[4096];

//Pairing message buffers
uint8_t m1[M1LENGTH] = { 0x68, 0x65, 0x6c, 0x6c, 0x6f, 0x20, 0x66, 0x72, 0x6f, 0x6d, 0x20 };  //"hello from "
uint8_t m2[UIDLENGTH + M1LENGTH];

//set bootup mode to PAIR
int currentMode = 1;

//indicate pair uid already exists in table
void neoPairExisting() {
  pixels.clear();
  pixels.setPixelColor(0, pixels.Color(0, 0, 80));
  pixels.setPixelColor(1, pixels.Color(0, 0, 80));
  pixels.setPixelColor(2, pixels.Color(0, 0, 80));
  pixels.setPixelColor(3, pixels.Color(0, 0, 80));
  pixels.setPixelColor(4, pixels.Color(0, 0, 80));
  pixels.setPixelColor(5, pixels.Color(0, 0, 80));
  pixels.show();
  //delay(1000);
  //pixels.clear();
  //pixels.show();
}
//indicate failed pair
void neoFailure() {
  pixels.clear();
  pixels.setPixelColor(0, pixels.Color(80, 0, 0));
  pixels.setPixelColor(1, pixels.Color(80, 0, 0));
  pixels.setPixelColor(2, pixels.Color(80, 0, 0));
  pixels.setPixelColor(3, pixels.Color(80, 0, 0));
  pixels.setPixelColor(4, pixels.Color(80, 0, 0));
  pixels.setPixelColor(5, pixels.Color(80, 0, 0));
  pixels.show();
  //delay(1000);
  //pixels.clear();
  //pixels.show();
}
//Flashes all lights to represent a Morse Code Dash. Does this x times
void pixelDash(int x) {
  for (int i = 0; i < x; i++) {
    for (int j = 0; j < 6; j++) {
      pixels.setPixelColor(j, pixels.Color(0, 40, 10));
      delay(40);  //DO NOT CHANGE! Without this delay, it all breaks. Suspect data transfer speed/clock issue.
    }
    pixels.show();
    delay(2000);
    pixels.clear();
    pixels.show();
    //Serial.print("DASH ");
  }
}

//Flashes all lights to represent a Morse Code Dot. Does this x times
void pixelDot(int x) {
  for (int i = 0; i < x; i++) {
    for (int j = 0; j < 6; j++) {
      pixels.setPixelColor(j, pixels.Color(0, 40, 10));
      delay(40);  //DO NOT CHANGE! Without this delay, it all breaks. Suspect data transfer speed/clock issue.
    }
    pixels.show();
    delay(1000);
    pixels.clear();
    pixels.show();
    //Serial.print("DOT ");
  }
}

//indicate successful pair
void neoSuccess() {
  pixels.clear();
  pixels.setPixelColor(0, pixels.Color(0, 80, 0));
  pixels.setPixelColor(1, pixels.Color(0, 80, 0));
  pixels.setPixelColor(2, pixels.Color(0, 80, 0));
  pixels.setPixelColor(3, pixels.Color(0, 80, 0));
  pixels.setPixelColor(4, pixels.Color(0, 80, 0));
  pixels.setPixelColor(5, pixels.Color(0, 80, 0));
  pixels.show();
  //delay(1000);
  //pixels.clear();
  //pixels.show();
}
//generate XOR key
void gk(int j, int o) {

  uint8_t b[4];
  uint8_t t1, t2, t3, t4;
  uint8_t b5 = j & 0xFF;
  uint8_t b6 = o & 0xFF;
  t1 = (4 * b5) + (2 * b6);
  b[0] = t1;  // 0x6E for 'n'

  t2 = ((3 * b6) + b5) + 1;
  b[1] = t2;  // 0x65 for 'e'

  t3 = (3 * b5) + (b6 * 2);
  b[2] = t3;  // 0x61 for 'a'

  t4 = (2 * b5) + (3 * b6) + 1;
  b[3] = t4;  // 0x72 for 'r'
  // Additional obfuscation: use bitwise operations and complex expressions
  uint8_t mask = 0xAA;
  for (int i = 0; i < 4; i++) {
    b[i] ^= mask;
    b[i] = ~b[i];
    b[i] = (b[i] << 4) | (b[i] >> 4);
    b[i] ^= mask;
    b[i] = ~b[i];
    b[i] = (b[i] >> 4) | (b[i] << 4);
  }
  for (int i = 0; i < 4; i++) {
    k[i] = b[i] ^ 0xFE;
  }
}

//Encryption Function 1
void dataEnc(uint8_t *s) {
  for (int i = 0; i < 4; i++) {
    s[i] ^= k[i];
  }
}

//Encryption Function 2
void dataEnc2(uint8_t *b){
  for (int i = 0; i < 3; i++){
    b[i] ^= k[i];
  }
}

void setup() {
  //md5 hash of UID
  uint8_t knownMD5[16] = {0xfd,0xd0,0x14,0x4f,0x31,0x13,0x83,0x64,0x51,0xe8,0x8e,0x8f,0x47,0x14,0xeb,0x88};

  //check integrity (MD5sum)
  md5.begin();
  md5.add(uid, sizeof(uid));
  md5.calculate();
  uint8_t hashBuf[16];
  md5.getBytes(hashBuf);
  for (int m = 0; m < 16; m++) {
    if (hashBuf[m] != knownMD5[m]) {
      currentMode = 0;
    }
  }
  
  //get current worm stored in flash
  currentWorm = getCurrentWorm();

  //generate the XOR key
  gk(13, 29);

  //decrypt UID in memory:
  dataEnc2(uid);

  Serial.begin(9600);
  Serial.println("######### WELCOME TO BSIDES ROANOKE 2024 #########");
  //Serial.println("-------Peer to Peer--------");
  memcpy(m2, m1, M1LENGTH);               //copy M1 into m2
  memcpy(m2 + M1LENGTH, uid, UIDLENGTH);  //copy the UID into M2, creating "hello from [UID]"
  pixels.begin();
  pixels.clear();
  pinMode(BUTTON_PIN, INPUT_PULLUP);
}

/*
Scan Mode
Reads the 4 byte UID from any NFC enabled tag/device then stores it into the Scan Table
*/
void scan() {
  NfcAdapter nfc2 = NfcAdapter(pn532spi);
  pixels.clear();

  nfc2.begin(true);
  for (int i = 0; i < NUMPIXELS; i++) {

    pixels.setPixelColor(i, pixels.Color(random(0, 128), random(0, 128), random(0, 128)));
    pixels.show();
    delay(200);
  }
  // Serial.println("aaaa");
  if (nfc2.tagPresent()) {
    for (int i = 0; i < NUMPIXELS; i++) {

      pixels.setPixelColor(i, pixels.Color(50, 100, 50));
      pixels.show();
      delay(200);
    }
    NfcTag tag = nfc2.read();
    //tag.print();
    String tagId = tag.getUidString();
    //Serial.println("Tag id");
    //Serial.println(tagId);
    uint8_t scannedUID[4];
    tag.getUid(scannedUID, 4);
    updateScanTable(scannedUID);
  }
  delay(1000);
}

// Polls for the presence of the Kiosk
bool pollKiosk() {
  pixels.clear();
  for (int i = 0; i < NUMPIXELS; i++) {

    pixels.setPixelColor(i, pixels.Color(80, 80, 0));
    pixels.show();
    delay(200);
  }
  uint8_t targetUid[] = { 0, 0, 0, 0, 0, 0, 0 };  // buffer for storing the target UID
  uint8_t uidLength;                              // Length of the UID (4 or 7 bytes depending on card type)
  uint8_t response[5];
  uint8_t responseLength;
  //delay(2000);
  bool success = nfc.initPassive(0, targetUid, &uidLength, 10000);
  if (success) {
    //Serial.println("Found a target!");
    //Serial.print("  UID Length: ");
    //Serial.print(uidLength, DEC);
    //Serial.println(" bytes");
    //Serial.print("  UID Value: ");
    //nfc.printHex(targetUid, uidLength);
    //Serial.println("");
    //Serial.print(uid[1],HEX);
    if (targetUid[1] == 0xC0) {
      //Serial.println("Kiosk is still here!");
      nfc.exchange(m2, sizeof(m2), response, &responseLength);
      return true;
    }
  } else {
    //Serial.println("Kiosk NOT found!");
  }
  return false;
}

//Sends the Scan Table to the Kiosk
bool sendScanTableToKiosk(uint16_t scanRecordNumBytes) {
  //Serial.println("SEND SCAN");
  uint8_t targetUid[] = { 0, 0, 0, 0, 0, 0, 0 };  // buffer for storing the target UID
  uint8_t uidLength;
  const uint8_t chunkSize = 250;
  uint8_t resBuf[chunkSize + 1];
  uint8_t resLength;
  bool lostConn = false;
  uint8_t s = nfc.initPassive(0, targetUid, &uidLength, 5000);
  if (s) {
    uint8_t chunkMessage[2];
    chunkMessage[1] = scanRecordNumBytes & 0xFF;
    chunkMessage[0] = (scanRecordNumBytes >> 8) & 0xFF;
    uint8_t s2 = nfc.exchange(chunkMessage, 2, resBuf, &resLength);
    for (uint16_t offset = 0; offset < scanRecordNumBytes; offset += chunkSize) {
      uint8_t success = nfc.initPassive(0, targetUid, &uidLength, 5000);
      if (lostConn) {
        offset -= chunkSize;
      }
      if (success) {
        uint8_t sendBytes = min(chunkSize, scanRecordNumBytes - offset);
        uint8_t success2 = nfc.exchange(tableBuf3 + offset, sendBytes, resBuf, &resLength);
        //Serial.print("Just exchanged: ");
        //Serial.print(sendBytes, DEC);
        //Serial.println(" bytes.");
        //Serial.print("offset: ");
        //Serial.println(offset);
        lostConn = false;
      } else {
        //Serial.println("Failed to talk to kiosk. We might be skipping a chunk! Rolling back...");
        if (offset != 0) {
          offset -= chunkSize;
        } else {
          lostConn = true;
        }
      }
    }
    //Serial.println("Done exchanging all chunks!");
    return true;
  }
  return false;
}

//Sends the Worm Table to the Kiosk
bool sendWormTableToKiosk(uint16_t wormRecordNumBytes) {
  //Serial.println("SEND WORM");
  uint8_t targetUid[] = { 0, 0, 0, 0, 0, 0, 0 };  // buffer for storing the target UID
  uint8_t uidLength;
  const uint8_t chunkSize = 249;
  uint8_t resBuf[chunkSize + 1];
  uint8_t resLength;
  bool lostConn = false;
  uint8_t s = nfc.initPassive(0, targetUid, &uidLength, 5000);
  if (s) {
    uint8_t chunkMessage[2];
    chunkMessage[1] = wormRecordNumBytes & 0xFF;
    chunkMessage[0] = (wormRecordNumBytes >> 8) & 0xFF;
    uint8_t s2 = nfc.exchange(chunkMessage, 2, resBuf, &resLength);
    for (uint16_t offset = 0; offset < wormRecordNumBytes; offset += chunkSize) {
      uint8_t success = nfc.initPassive(0, targetUid, &uidLength, 5000);
      if (lostConn) {
        offset -= chunkSize;
      }
      if (success) {
        uint8_t sendBytes = min(chunkSize, wormRecordNumBytes - offset);
        uint8_t success2 = nfc.exchange(tableBuf2 + offset, sendBytes, resBuf, &resLength);
        //Serial.print("Just exchanged: ");
        //Serial.print(sendBytes, DEC);
        //Serial.println(" bytes.");
        //Serial.print("offset: ");
        //Serial.println(offset);
        lostConn = false;
      } else {
        //Serial.println("Failed to talk to kiosk. We might be skipping a chunk! Rolling back...");
        if (offset != 0) {
          offset -= chunkSize;
        } else {
          lostConn = true;
        }
      }
    }
    //Serial.println("Done exchanging all chunks!");
    return true;
  }
  return false;
}
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
void loop() {
  const int serialCommandLength = 32;
  char receivedChars[serialCommandLength];

  char commandChar;
  static int sCount = 0;
  char endMarker = '\n';
  pixels.clear();
  static int interval = random(250, 350);
  if (currentMode == 0) {
    badgeLock();
  }
  while (Serial.available() > 0 && newCommand == false) {
    commandChar = Serial.read();
    if (commandChar != endMarker) {
      receivedChars[sCount] = commandChar;
      sCount++;
      if (sCount >= serialCommandLength) {
        sCount = serialCommandLength - 1;
      }
    } else if (commandChar == endMarker) {
      receivedChars[sCount] = '\0';  //string terminated
      sCount = 0;
      newCommand = true;
    }
    //newCommand = false;
  }
  if (newCommand) {
    //Serial.println(receivedChars);
    if (strcmp("help", receivedChars) == 0 || strcmp("?", receivedChars) == 0) {
      //Serial.println("HELP_HERE");
      Serial.println("<HELP MENU>");
      Serial.println("---------- Command : Info ----------");
      Serial.println("help : Prints this table");
      //Serial.println("get_uid : Get your badge's unique ID");
      Serial.println("set_mode MODE : Sets the running mode on the badge to MODE");
      Serial.println("get_table TABLE : Outputs the number of records + each record in table TABLE");
      Serial.println("light NUM : Runs the light puzzle NUM on demand");
      Serial.println("flag : Gives a flag");
    } else if (strcmp("flag", receivedChars) == 0) {
      Serial.println("Which one?");
    } else if (strncmp("light", receivedChars, 5) == 0 && receivedChars[5] == ' ') {
      int lightType = (int)(receivedChars[6]) - '0';
      if (lightType == 1) {
        Serial.println("Got it. Going to run light 1.");
        puzzle1();
      } else if (lightType == 2) {
        Serial.println("Got it. Going to run light 2.");
        puzzle2();
      } else if (lightType == 3) {
        Serial.println("Got it. Going to run light 3.");
        puzzle3();
      } else {
        Serial.println("Which puzzle did you want to run???");
      }
    } else if (strncmp("flag", receivedChars, 4) == 0 && receivedChars[4] == ' ') {
      int flagType = (int)(receivedChars[5]) - '0';
      if (flagType == 1) {
        char flagChar;
        static int sFlagCount = 0;
        char endFlagMarker = '\n';
        bool flagCommand = false;
        Serial.println("We are an army of undead, though we were never alive. We quench the mightiest of walls and eat all your resources. What are we?");
        //Here we have to start a timer using millis() (10 seconds) to wait for the answer input. Since We are in a nested reading loop already, this is the best way to read from Serial
        unsigned long startTime = millis();
        while (millis() - startTime < 10000 && !flagCommand) {
          while (Serial.available() > 0) {
            //Serial.println("inside of flag1 answer read");
            flagChar = Serial.read();
            if (flagChar != endFlagMarker) {
              receivedChars[sFlagCount] = flagChar;
              sFlagCount++;
              if (sFlagCount >= serialCommandLength) {
                sFlagCount = serialCommandLength - 1;
              }
            } else if (flagChar == endFlagMarker) {
              receivedChars[sFlagCount] = '\0';  //string terminated
              sFlagCount = 0;
              flagCommand = true;
              //Serial.println(receivedChars);
            }
          }
        }
        //Serial.println("outside of flag1 answer read");
        if (flagCommand) {

          if (strcmp("botnet", receivedChars) == 0) {
            Serial.println("Yes! Flag:");
            printFlag1(0x11);
          } else {
            Serial.println("no....");
          }
        } else {
          Serial.println("No response received in time (TIMEOUT)");
        }
      } else if (flagType == 2) {
        startInterview();
      } else {
        Serial.println("I don't know which flag that is...");
      }
    } else if (strncmp("set_mode", receivedChars, 8) == 0 && receivedChars[8] == ' ') {
      int mode = (int)(receivedChars[9]) - '0';
      if (mode >= 1 && mode <= 4) {
        Serial.print("SET_MODE with value: ");
        Serial.println(mode);
        currentMode = mode;
      } else {
        Serial.println("MODE must be between 1 and 4.");
      }
    //} else if (strcmp("get_uid", receivedChars) == 0) {
    //  Serial.print("Your UID is: ");
    //  for (uint8_t i = 0; i < UIDLENGTH; i++) {
    //    Serial.print(uid[i], HEX);
    //  }
    //  Serial.println();
    } else if (strcmp("get_worm", receivedChars) == 0) {
      Serial.print("Your WORM is: ");
      Serial.println(currentWorm, HEX);
    } else if (strncmp("get_table", receivedChars, 9) == 0 && receivedChars[9] == ' ') {
      char *tableType = &receivedChars[10];
      if (strcmp(tableType, "scan") == 0) {
        Serial.println("GET_TABLE: SCAN");
        int tableSize = numRecordsScanTable();
        Serial.print("Number of entries in scan table: ");
        Serial.println(tableSize);
        //uint8_t tableBuf[tableSize * 4];
        getScanTable(tableBuf1);
        for (uint16_t i = 0; i < (tableSize * 4); i++) {
          Serial.print(tableBuf1[i], HEX);
          Serial.print(' ');
        }
        Serial.print('\n');
      } else if (strcmp(tableType, "worm") == 0) {
        Serial.println("GET_TABLE: WORM");
        int tableSize = numRecordsWormTable();
        Serial.print("Number of entries in worm table: ");
        Serial.println(tableSize);
        //uint8_t tableBuf[tableSize * 3];
        getWormTable(tableBuf1);
        for (uint16_t i = 0; i < (tableSize * 3); i++) {
          Serial.print(tableBuf1[i], HEX);
          Serial.print(' ');
        }
        Serial.print('\n');
      } else if (strcmp(tableType, "pair") == 0) {
        Serial.println("GET_TABLE: PAIR");
        int tableSize = numRecordsPairTable();
        Serial.print("Number of entries in pair table: ");
        Serial.println(tableSize);
        //uint8_t tableBuf[tableSize * 3];
        getPairTable(tableBuf1, false);
        for (uint16_t i = 0; i < (tableSize * 3); i++) {
          Serial.print(tableBuf1[i], HEX);
          Serial.print(' ');
        }
        Serial.print('\n');

      } else {
        Serial.println("Unknown table type");
      }
    } else {
      Serial.print("Unknown command: ");
      Serial.print(receivedChars);
      Serial.println(". Type help for commands.");
    }
    newCommand = false;
  }
  //Serial.println(receivedChars);
  if (currentMode == MODE_PAIR) {
    Serial.println("HANDSHAKE MODE");
    //Serial.print("WORM VAL:");
    //Serial.println(currentWorm, HEX);
    initializer1();
    delay(interval);
    target1();
    delay(interval);
  } else if (currentMode == MODE_SCAN) {
    Serial.println("SCAN MODE");
    scan();
  } else if (currentMode == MODE_KIOSK) {
    Serial.println("KIOSK MODE");
    kiosk();
    //sendPairTableToKiosk();
    delay(5000);
  } else if (currentMode == MODE_PUZZLE) {
    int puzzle_num = 1;
    while(currentMode == MODE_PUZZLE) {
        delay(200);
        if(puzzle_num == 1) {
          Serial.println("PUZZLE 1");
          puzzle1();
          puzzle_num = 2;
        }
        else if (puzzle_num == 2) {
          Serial.println("PUZZLE 2");
          puzzle2();
          puzzle_num = 3;
        }
        else if (puzzle_num == 2) {
          Serial.println("PUZZLE 3");
          puzzle3();
          puzzle_num = 1;
        }
    }
  }
}


//This next section contains code to translate button presses from SW3 to morse code. Taken from https://www.hackster.io/vladakrsmanovic/arduino-morse-code-machine-709cc5.
//Big thanks to Vladimir Krsmanovic
//Note: Conditions have been reversed since we start our button logic on HIGH (1) NOT LOW (0)

//Morse Code setup
int buttonState = LOW;      //0
int lastButtonState = LOW;  //0
const int buttonPin = BUTTON_PIN;
int pause_value = 250;  // depending on your skill and how fast your fingers are you can change this value to make typing a message faster or slower
long signal_length = 0;
long pause = 0;
String morse = "";
String dash = "-";
String dot = "*";
boolean cheker = false;
boolean linecheker = false;
//setup core1
void setup1() {
}
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

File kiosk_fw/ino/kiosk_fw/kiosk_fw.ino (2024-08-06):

/*
BSides Roanoke 2024 Kiosk FW
Wrote by BenTheCyberOne with the help of doc and KoopaTroopa8

Free to edit and distribute as you please

*/

#include "SPI.h"
#include "PN532_SPI.h"
#include "llcp.h"
#include "snep.h"
#include <NfcAdapter.h>

PN532_SPI pn532spi(SPI, 17);
SNEP nfc(pn532spi);
//Static Kiosk UID
uint8_t uid[3] = { 0xC0, 0xFE, 0xED };

//Buffer for reading tables from badge (max size is 4096)
uint8_t badgeBuf[4096];

//Buffer for reading misc messages from Badge, table int sizes
uint8_t readBuf[252];

//Message buffer for polling, init kiosk <-> badge
uint8_t m1[11] = { 0x68, 0x65, 0x6c, 0x6c, 0x6f, 0x20, 0x66, 0x72, 0x6f, 0x6d, 0x20 };  //"hello from "
uint8_t m2[14];

void setup() {
  Serial.begin(9600);
  //Serial.println("Connected");

  memcpy(m2, m1, 11);       //copy M1 into m2
  memcpy(m2 + 11, uid, 3);  //copy the UID into M2, creating "hello from [UID]"
}
int count = 0;
bool step1, step2, step3;

void loop() {
  step1 = initKiosk();
  while (step1) {
    step2 = getBadgePairData();
    if (!step2) {
      step1 = false;
      break;
    }
    step2 = getBadgeWormData();
    if (!step2) {
      step1 = false;
      break;
    }
    step2 = getBadgeScanData();
    if (!step2) {
      step1 = false;
      break;
    }
    while (step2) {
      //delay(3000);
      step3 = pollBadge();
      if (!step3) {
        step1 = false;
        step2 = false;
        step3 = false;
        //Serial.println("No longer polling...");
        break;
      }
    }
  }
  //pollBadge();
  delay(2000);
}

//Reads the Scan Table data from the badge and outputs to Serial (webapp)
bool getBadgeScanData() {
  uint8_t resLength;
  const uint8_t chunkSize = 250;
  uint8_t resBuf[chunkSize + 1];
  //bool lostConn = false;
  uint8_t s = chunkSize;
  delay(2500);  // required for badge to finish setting up table buffer
  int16_t r = nfc.read(readBuf, sizeof(readBuf), uid, 4000);
  if (r > 0) {
    //Serial.println("SCAN TRANSFER");
    uint16_t numBytesExpected = readBuf[1] | (readBuf[0] << 8);
    //Serial.print("Number of bytes expected: ");
    //Serial.println(numBytesExpected);
    //Serial.print("Chunks=");
    //Serial.println(((numBytesExpected/chunkSize)+1),DEC);
    //Serial.println("EOT");
    delay(2000);
    for (uint16_t offset = 0; offset < numBytesExpected; offset += s) {
      //delay(1500); This delay is no longer needed - we can loop and reset the offset if we fail a cycle!
      //if (lostConn) {
      //  offset -= chunkSize;
      //}
      uint8_t w = nfc.read(readBuf, sizeof(readBuf), uid, 2000);
      if (w > 0 && w < 254) {
        //Serial.println("Successfully got chunk!");
        //Serial.println(w, DEC);
        memcpy(badgeBuf + offset, readBuf, w);
        //lostConn = false;
        //Serial.print("PART_");
        //Serial.println((offset/chunkSize),DEC);
        //for(int i = 0; i < w; i++){
        //  Serial.print(readBuf[i], HEX);
        //}
        //Serial.println();
        //Serial.println("EOT");
        s = w;
      } else {
        //Serial.println("Failed to read from badge. We might be skipping a chunk! Rolling back...");
        //lostConn = true;
        if (offset != 0) {
          offset -= s;
        } else {
          //lostConn = true;
          s = 0;
        }
      }
    }
    Serial.println("PART_2");
    //Serial.println("current badgeBuf:");
    if (numBytesExpected > 0) {
      for (uint16_t i = 0; i < numBytesExpected; i++) {
        Serial.print(badgeBuf[i], HEX);
      }
    }
    Serial.println();
    Serial.println("EOT");

    //Serial.println();
    return true;
  }
  return false;
}

//Reads the Worm Table data from the badge and outputs to Serial (webapp)
bool getBadgeWormData() {
  uint8_t resLength;
  const uint8_t chunkSize = 249;
  uint8_t resBuf[chunkSize + 1];
  bool lostConn = false;
  uint8_t s = chunkSize;
  //Serial.println("WORM TRANSFER 1");
  delay(2500);  // required for badge to finish setting up table buffer
  int16_t r = nfc.read(readBuf, sizeof(readBuf), uid, 4000);
  if (r > 0) {
    //Serial.println("WORM TRANSFER 2");
    uint16_t numBytesExpected = readBuf[1] | (readBuf[0] << 8);
    //Serial.print("Number of bytes expected: ");
    //Serial.println(numBytesExpected);
    //Serial.print("Chunks=");
    //Serial.println(((numBytesExpected/chunkSize)+1),DEC);
    //Serial.println("EOT");
    delay(2000);
    for (uint16_t offset = 0; offset < numBytesExpected; offset += s) {
      //delay(1500); This delay is no longer needed - we can loop and reset the offset if we fail a cycle!
      //if (lostConn) {
      //  offset -= s;
      //}
      uint8_t w = nfc.read(readBuf, sizeof(readBuf), uid, 2000);
      if (w > 0 && w < 252) {
        //Serial.println("Successfully got chunk!");
        //Serial.println(w, DEC);
        memcpy(badgeBuf + offset, readBuf, w);
        //Serial.print("PART_");
        //Serial.println((offset/chunkSize),DEC);
        //for(int i = 0; i < w; i++){
        //  Serial.print(readBuf[i], HEX);
        // }
        //Serial.println();
        //Serial.println("EOT");
        //lostConn = false;
        s = w;
      } else {
        //Serial.println("Failed to read from badge. We might be skipping a chunk! Rolling back...");
        //lostConn = true;
        if (offset != 0) {
          offset -= s;
        } else {
          s = 0;
          //lostConn = true;
        }
      }
    }
    //Serial.print("Offset:");
    //Serial.println(offset, DEC);
    //Serial.println("current badgeBuf:");
    Serial.println("PART_1");
    if (numBytesExpected > 0) {
      for (uint16_t i = 0; i < numBytesExpected; i++) {
        Serial.print(badgeBuf[i], HEX);
      }
    }
    Serial.println();
    Serial.println("EOT");
    //Serial.println();
    return true;
  }
  return false;
}
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
